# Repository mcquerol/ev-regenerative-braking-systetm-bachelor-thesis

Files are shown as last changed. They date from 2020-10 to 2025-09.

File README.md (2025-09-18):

# ev-regenerative-braking-system-bachelor-thesis

Initial README file.

Report can be found on Researchgate ->

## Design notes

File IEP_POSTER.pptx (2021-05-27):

## A comparison of li-ion cells and supercapacitors in the efficiency of a regenerative braking system for EVs

Introduction
Electric vehicles (EVs) have been around for many years and have since become increasingly popular in society. The rechargeable lithium-ion battery was commercialised in 1985 and since then it has become widespread in many commercial applications such as laptops, cell phones, alarm systems and recently EVs.
A regenerative braking system in an EV consists of taking the car’s kinetic energy and converting it into electrical energy; this energy is stored in Li-ion cells. Recent developments in solid-state storage devices (supercapacitors) could show not only improved performance, but a more environmentally friendly solution.
This project will be a comparison of Li-ion and supercapacitor battery technologies used in the context of a regenerative braking system. The efficiency will be measured by speeding up a DC motor to a set speed for both batteries then measuring the capacities of both batteries after they have been recharged with the back-emf of the DC motor.
Given the financial and time constrains of the project, this will be produced on a small scale, hence why a DC motor is used. The capacities of the Li-ion and supercapacitor battery packs will be limited (but approximately equal to ensure a fair comparison) because of the limited budget of £75.

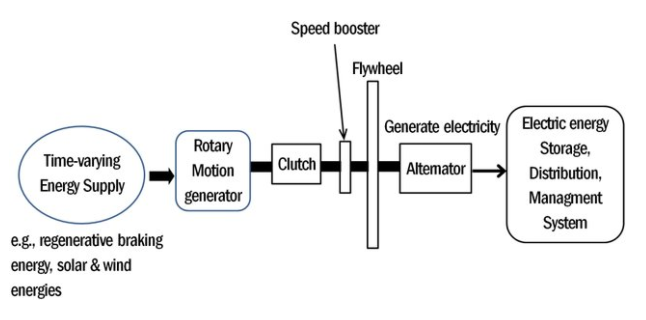
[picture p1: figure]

100448597
Supervisor: David Wilson

Results
For each of the storage devices, the current was motor was sped up to certain (approximate) speeds and the current output of the buck converter was measured. Next, the time the LEDs stayed on was measured using a stopwatch. The % of battery filled was calculated and graphed vs the speed of the motor.
% charged[(Wh)/(Wh)]=((V×I×s)/3600)/(max. capacity)×100%
The supercapacitor proved to have regenerated almost double the amount of the Li-ion cell. This is because the supercapacitor is built to charge and discharge more quickly than the Li-ion cell.
In May 2016, a Tibetan river was contaminated by a nearby mine leak which killed all the fish and destroyed the surrounding ecosystem. The higher the demand for Lithium batteries, the higher the risk of pollution to the environment; cases like these pose the question of needing a more sustainable means of energy storage. Lithium mines around the world are not always in the best working conditions, not supporting the workers with protective equipment can be detrimental to their health and can lead to a disinterest in the future workforce.

Conclusion
Li-ion cells and supercapacitors are both very promising for the future of battery storage technology. In principle, Li-ion batteries are better for long range applications whereas supercapacitors are better for applications that require quick bursts of energy; this was seen through the various measurements taken from the prototype.
EVs are a new, emerging technology that is constantly changing. Now most if not all EV companies (primarily Tesla) are in the Li-ion market. Unfortunately, supercapacitors have not been made widely available yet in the EV market. Supercapacitors have many advantages in terms of the way they store and manage stored power, but the main disadvantage is that there is a very large cost that comes with these devices. With climate change being a concern, this only begs the change to a more sustainable and easy-to-obtain method of energy storage.

PCB and prototype
The brain of this small-scale regenerative braking system is the PIC18F25K22 microcontroller, it controls all the inputs and outputs of the system. The two storage devices: the supercapacitor and Li-ion cell have two different operating voltages (2.5V and 3.7V). The user must have a choice to which one is used at a given time so one of the inputs is selecting the storage device. This tells the PIC how it should step down the back-emf coming from the motor.
A simple button or switch can be used to enable the motor to start moving, once it reaches a certain speed, it is turned off and the back-emf is fed through the buck converter into the storage device. The boost converter then takes said voltage and steps it back up at a level high enough for the PIC to measure current. This is done through a simple voltage divider for the voltage and the current is measured using a transconductance amplifier.
The speed of the wheel attached to the motor and is measured with an optocoupler. The optocoupler is used to measure how many rotations occur in one second and the RPM can be calculated. It is through this measurement that the motor can be stopped after x RPM.

References
Barrera, P. (2020, August 20). Top Lithium Production by Country | Australia is First | INN. Investingnews. https://investingnews.com/daily/resource-investing/battery-metals-investing/lithium-investing/lithium-production-by-country/
Bousbaine, A. (2020). Lecture 5-Boost converters-V1-BB (p. 18).
Cordis. (2018). Clean and green supercapacitors for energy efficiency and transport applications | Results In Brief | CORDIS | European Commission. https://cordis.europa.eu/article/id/148917-clean-and-green-supercapacitors-for-energy-efficiency-and-transport-applications
Emmerich. (2017). 18650 Li ion cell. https://asset.conrad.com/media10/add/160267/c1/-/en/000251007DS01/datasheet-251007-emmerich-icr-18650nh-sp-non-standard-battery-rechargeable-18650-cable-li-ion-37-v-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

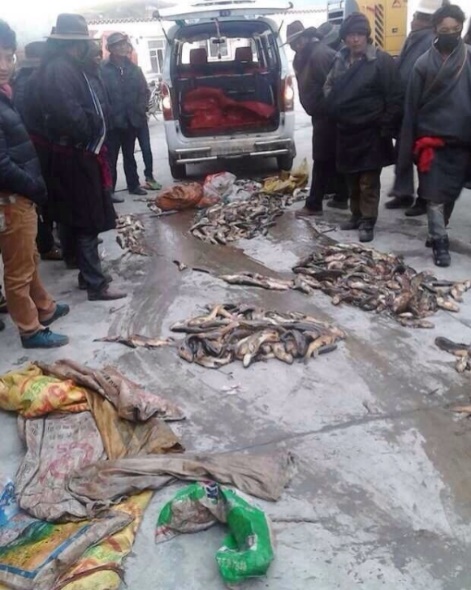
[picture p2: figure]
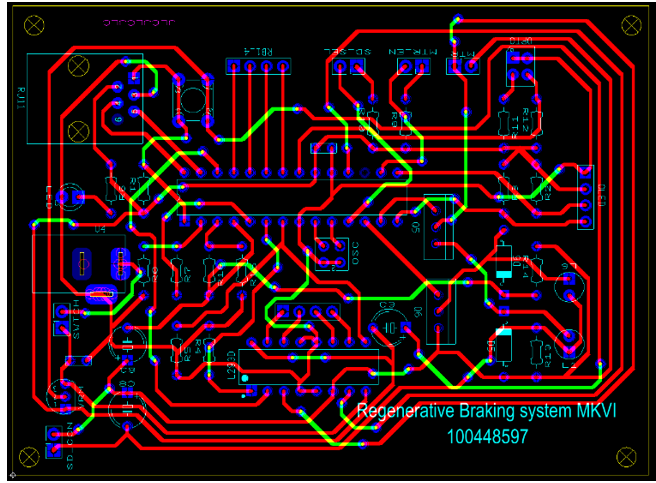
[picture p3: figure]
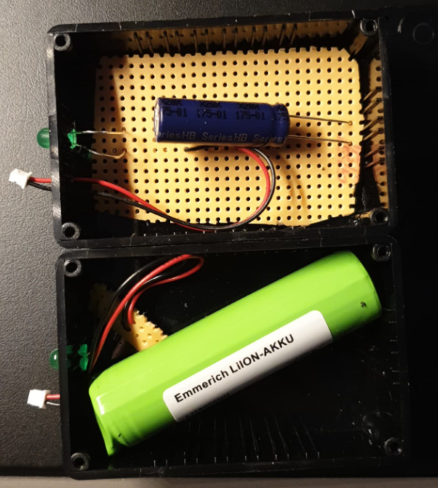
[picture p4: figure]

Li-ion cell & supercapacitor

Storage device

Main system

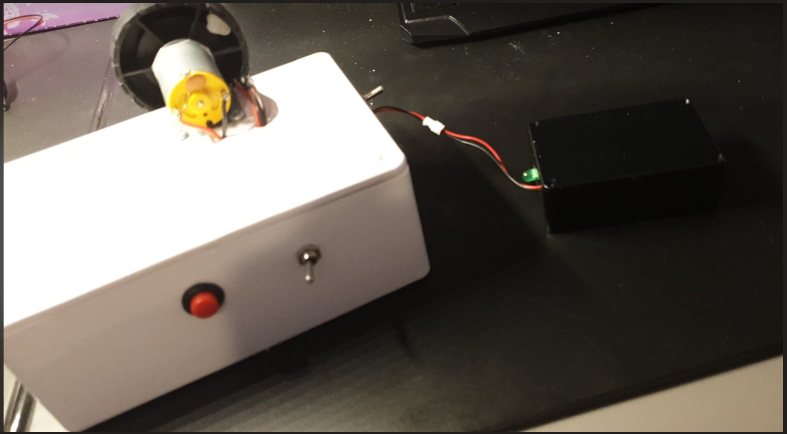
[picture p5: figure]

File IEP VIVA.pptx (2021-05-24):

## A comparison of Li-ion cells and supercapacitors in the efficiency of a regenerative braking system for EVs

By: Mateo Ceballos Querol
100448597
H600 (Hons) BEng Electrical and Electronic Engineering
Supervisor : David Wilson

## Outline

- Introduction
- Aims
- Motivation
- Initial ideas
- Conceptual flowchart
- Design
  - Schematic
  - PCB
  - Prototype
- Coding flowchart
- Results & Analysis
  - Graphs
  - Sustainability & Ethics
- Future recommendations
- Conclusions
- References

## Introduction

- Rise of EVs
- Regenerative braking system
- Concerns of battery technology
- Environmental and ethical issues
- Create prototype

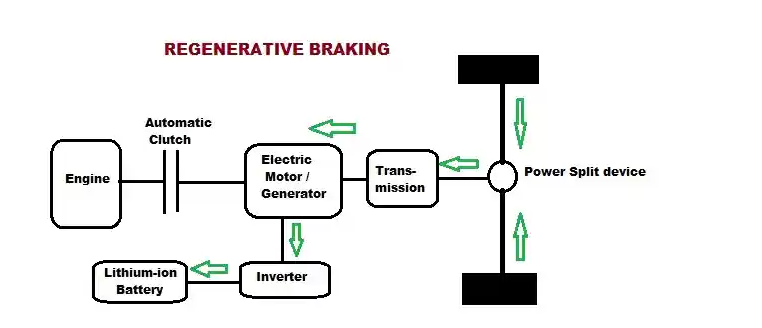
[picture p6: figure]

(Smith, 2014)

## Aims

  - Design and build a regenerative braking system using a DC motor.
  - Measure how much power is regained into each “battery pack” from the DC motor.
  - Provide a more ethically and environmentally sustainable means of manufacturing batteries.
  - Justify the potential change from LI-ion to supercapacitors as the potential power source for EVs.

## Motivation

- Science & Tech
- Electric Vehicles
- Sustainability
- Future interest in embedded systems

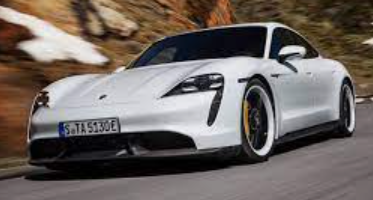
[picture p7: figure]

(Miller, 2019)

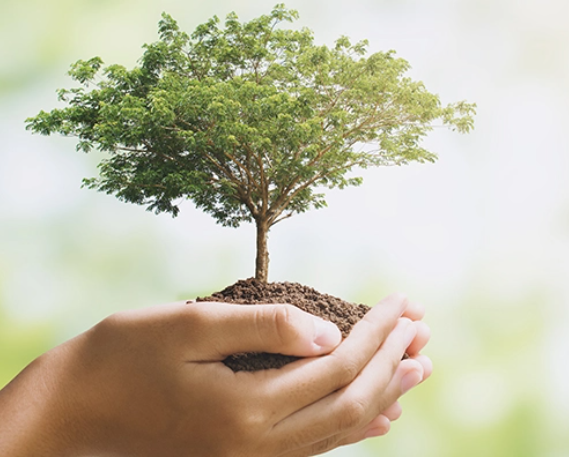
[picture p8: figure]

(Stuart, 2018)

## Initial ideas

- Plan A: Create compact enclosure/PCB
- Develop regenerative braking system as in an EV
- Send data to a PC via USB
- Plan B: Simulink model, more freedom

## Conceptual flowchart

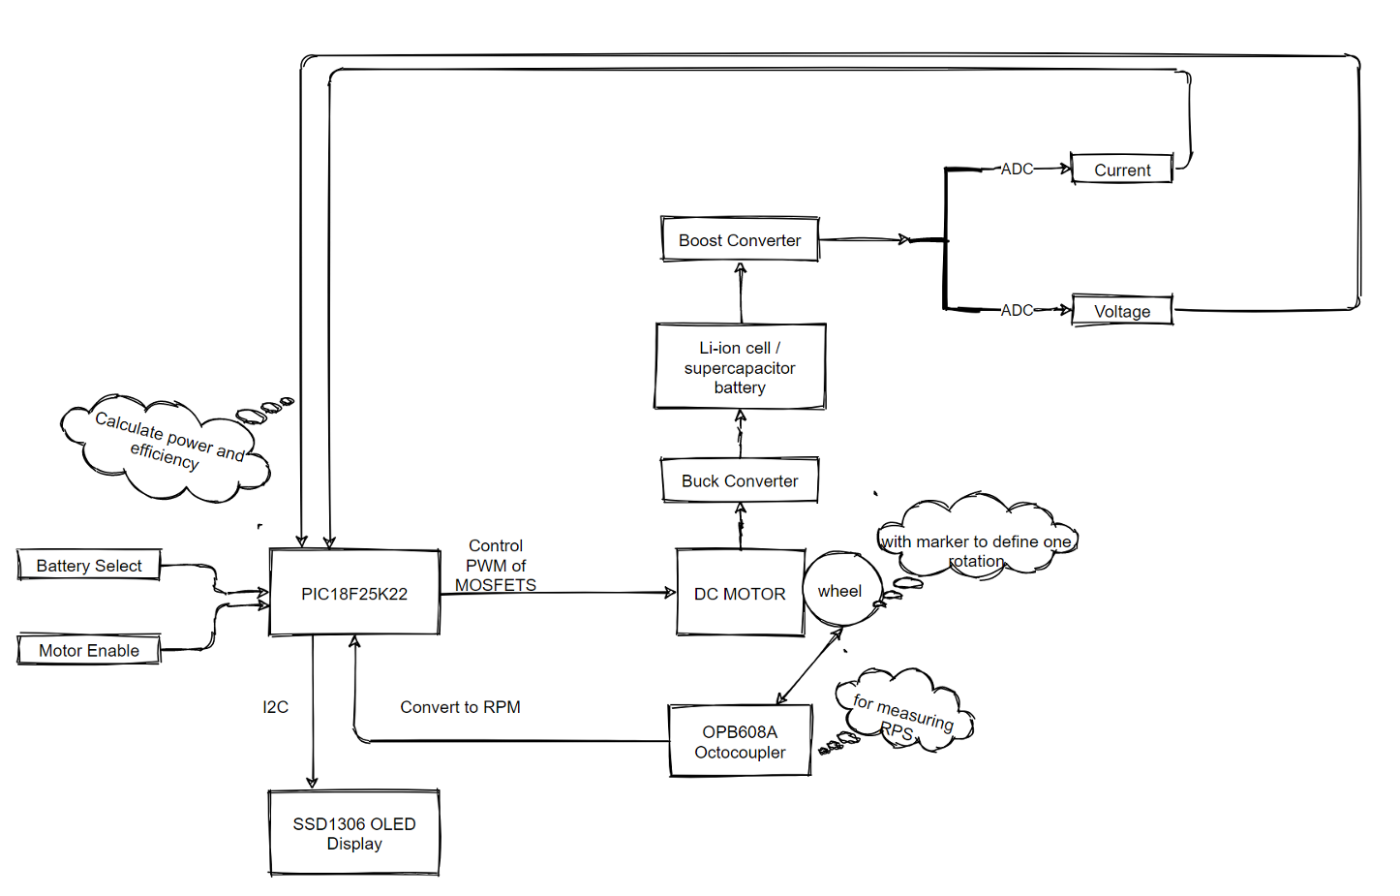
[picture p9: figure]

## Design - Schematic

- PIC18F25K22
- Motor control
- ADC
- I2C
- Optocoupler

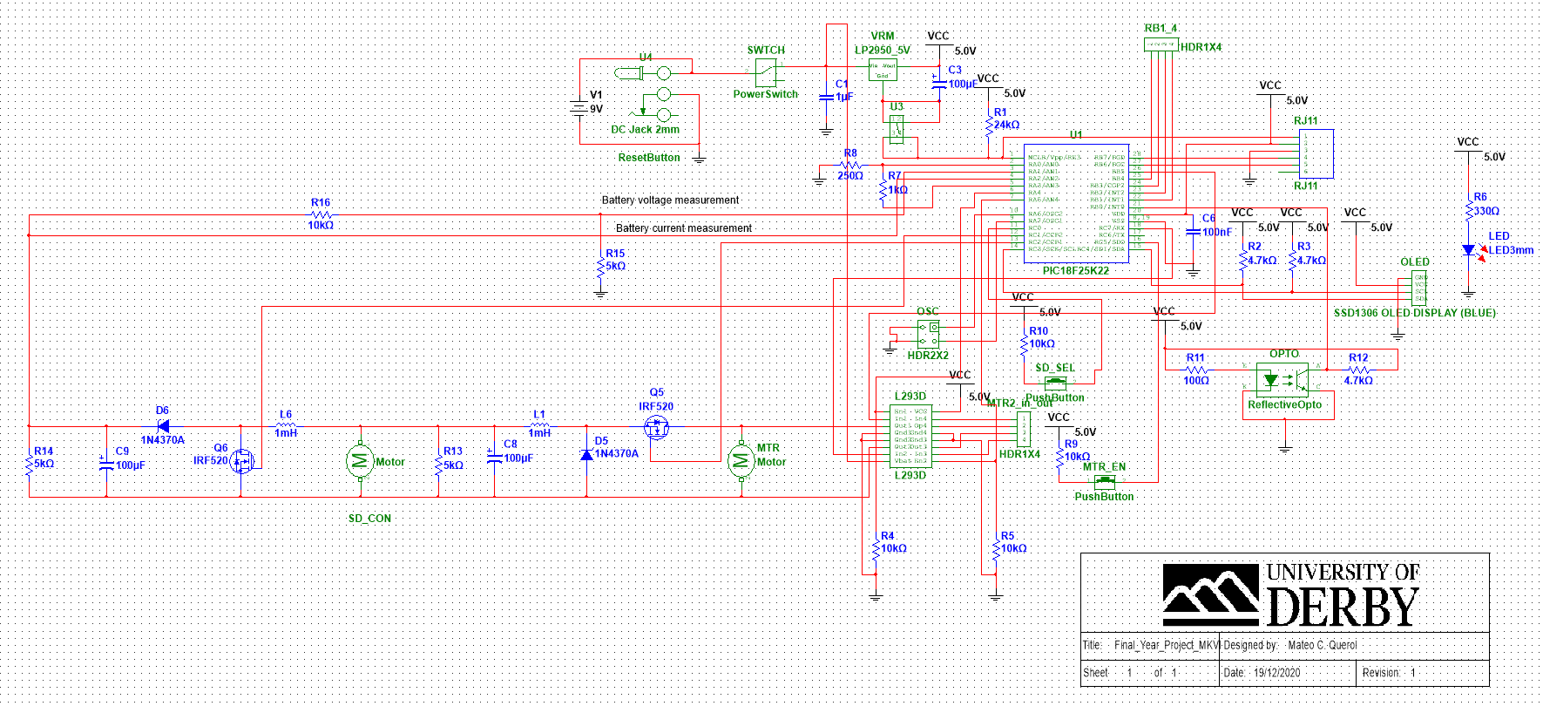
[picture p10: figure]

## Design - PCB

- Arduino-inspired design
- 6 iterations
- JLCPCB

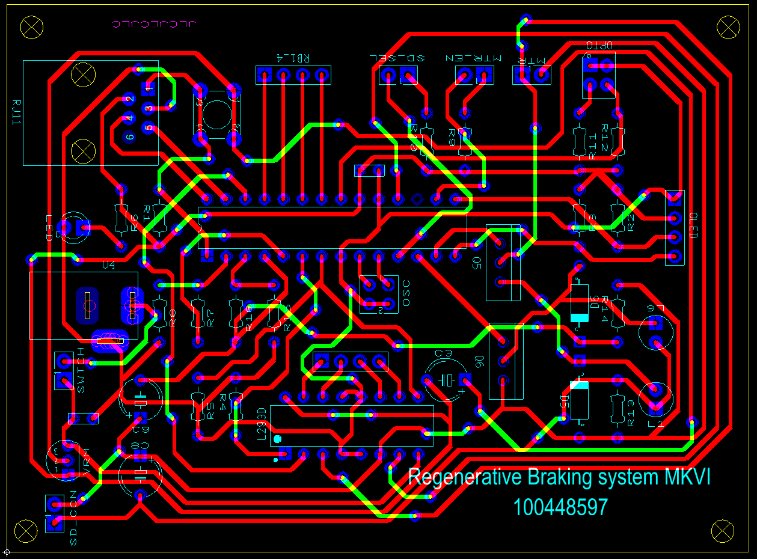
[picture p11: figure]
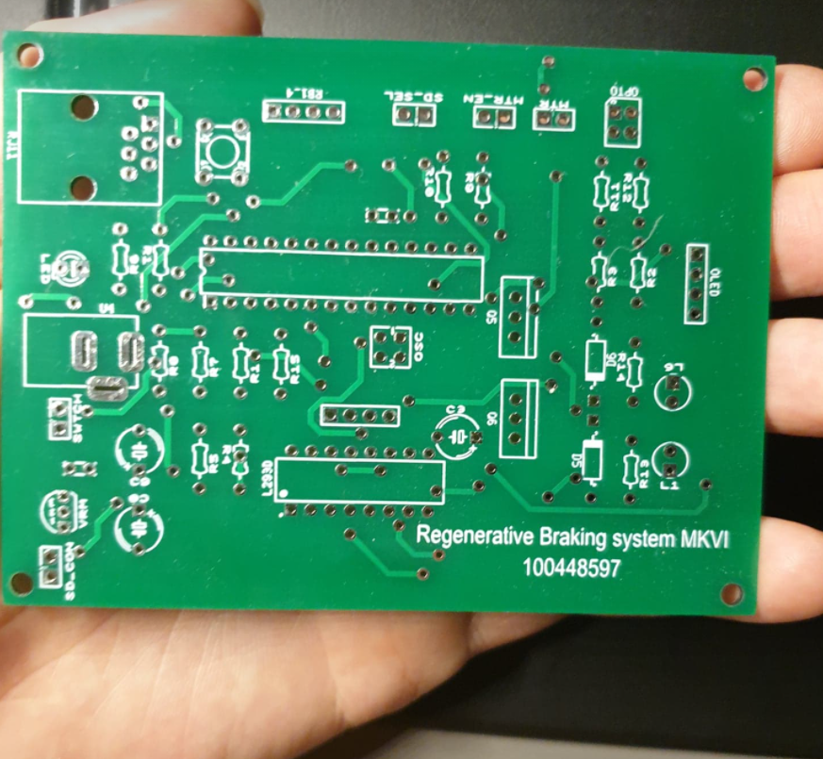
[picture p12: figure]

## Design - Prototype

- Modular design

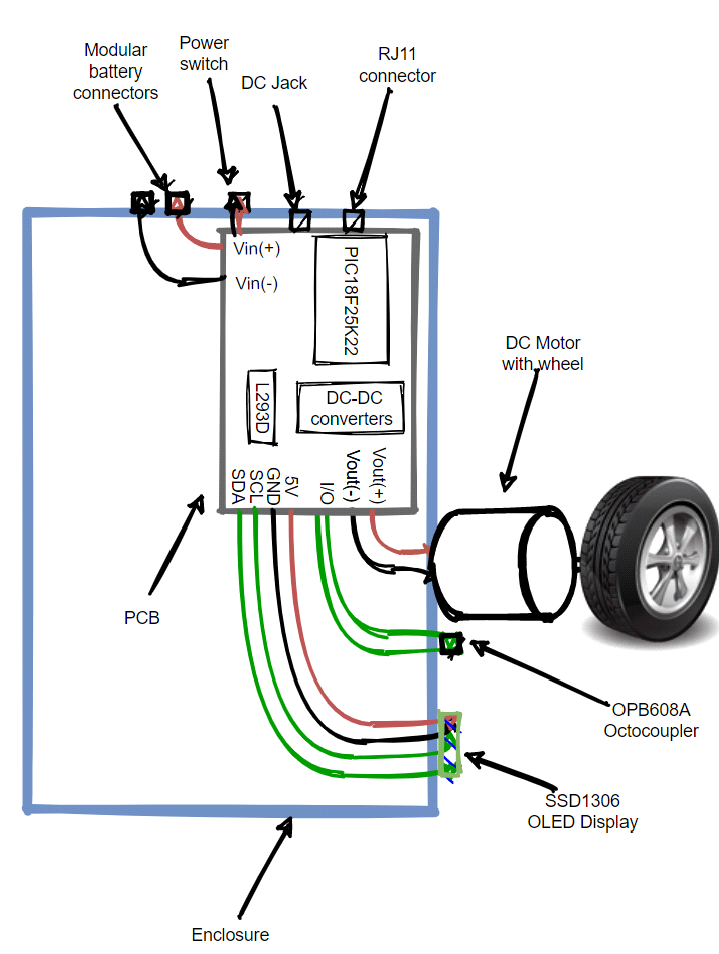
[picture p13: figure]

Storage device


Li-ion and supercapacitor


Main system

## Coding flowchart

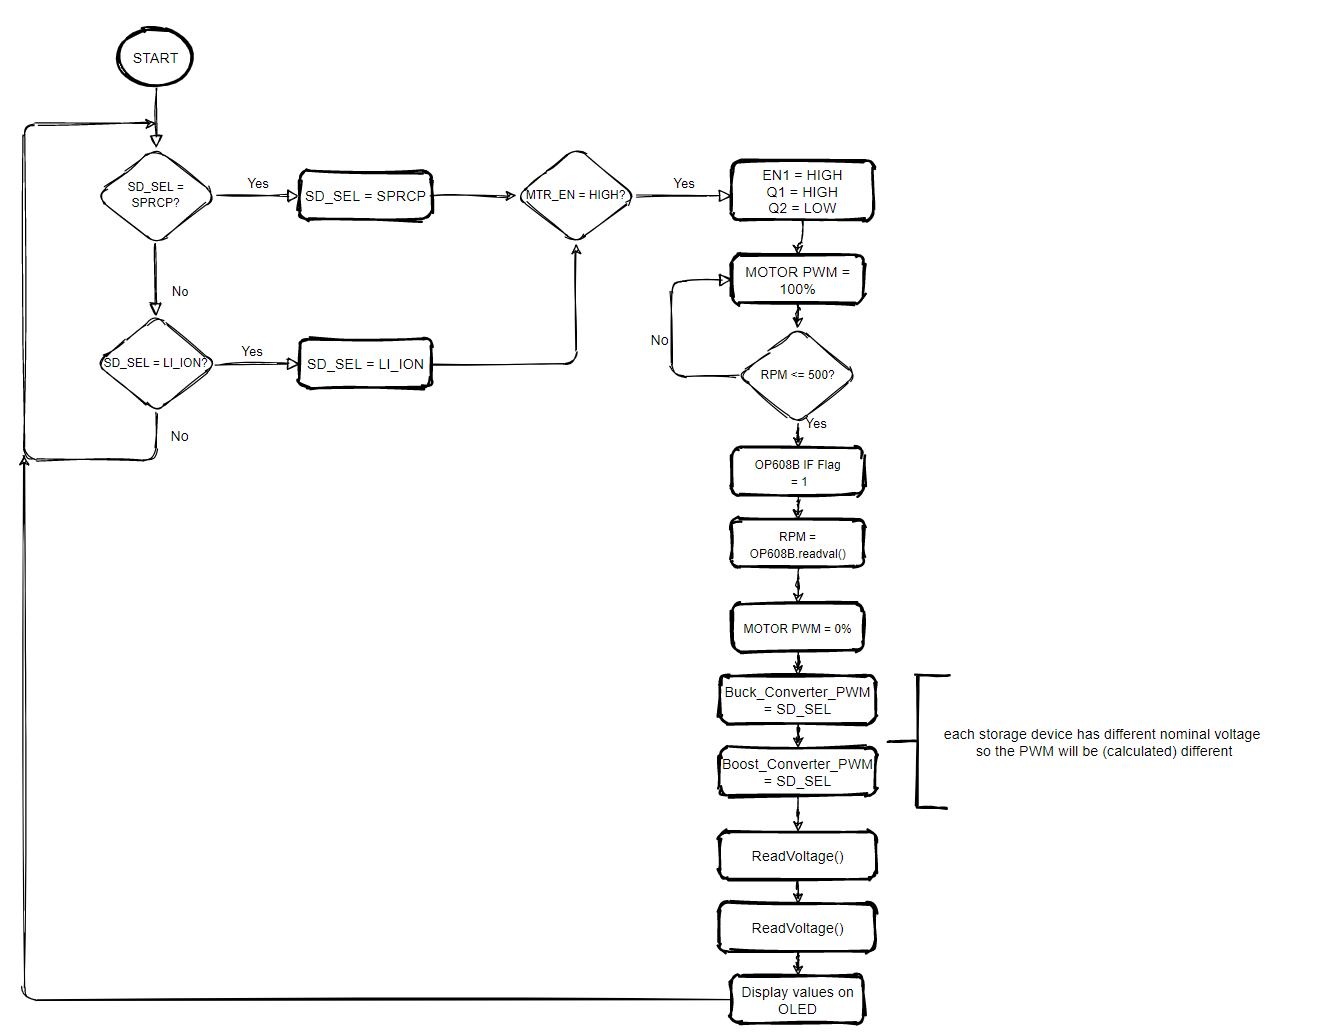
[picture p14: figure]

## Results & Analysis - Graphs

- Li-ion capacity : 8.14Wh
- Supercapacitor capacity : 8.17mWh

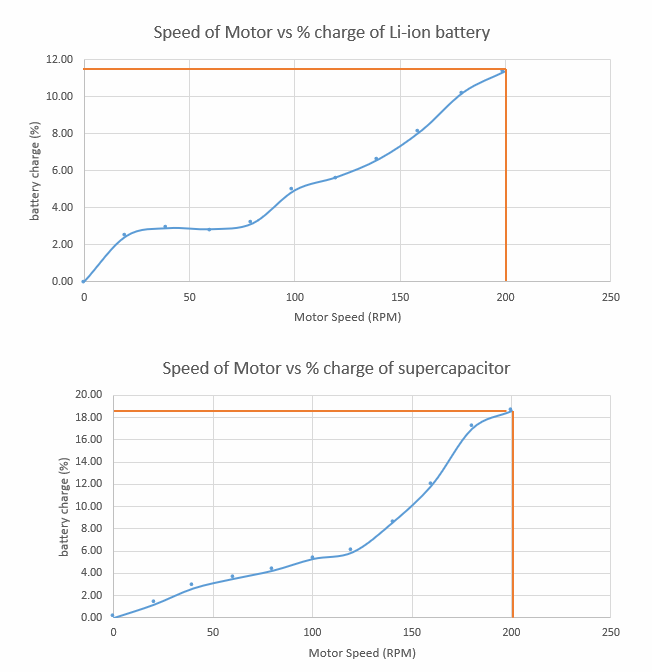
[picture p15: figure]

## Results & Analysis - Graphs

- Max motor speed is 210 RPM
- Max motor power is approx. 1.6W

## Results & Analysis – Sustainability & ethics

- Mine leaks
- Underpaid, non-safe working conditions
- Import/Export
- EU, circular economy

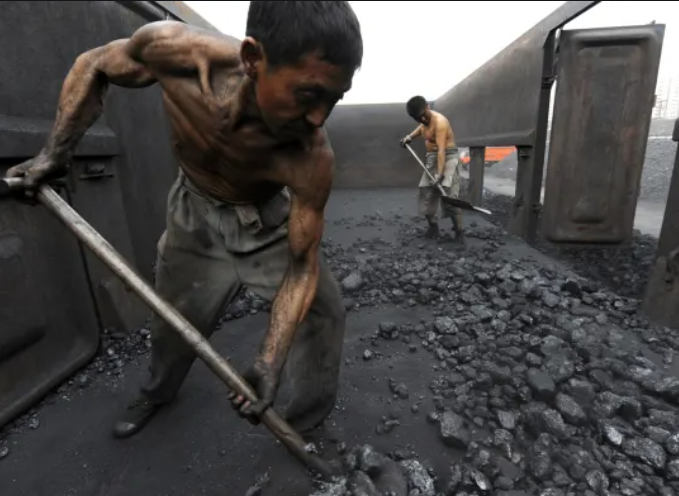
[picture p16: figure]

(Hornby, 2020)

(Song, 2016)

## Future recommendations

- SMD components
- Larger Motor
- Equal storage device capacities
- Possible hybrid Li-ion-supercapacitor battery

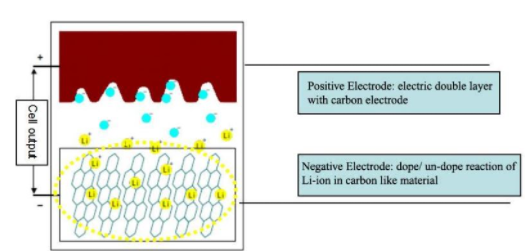
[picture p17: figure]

(Keenan, 2017)

## Conclusion

- Total cost of project = £60.25
- Environmental footprint
- Li-ion batteries are still optimal
- Increase in EV popularity

## References

- Emmerich. (2017). 18650 Li ion cell. https://asset.conrad.com/media10/add/160267/c1/-/en/000251007DS01/datasheet-251007-emmerich-icr-18650nh-sp-non-standard-battery-rechargeable-18650-cable-li-ion-37-v-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
- fleeteurope. (2018). How ethically is lithium sourced by OEMs? | Fleet Europe. https://www.fleeteurope.com/fr/connected-financial-models/global-europe/analysis/how-ethically-lithium-sourced-oems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 ion battery&curl=1
- Garcia, G. (2014). (3) (PDF) Potential environmental impacts of Li-ion batteries and supercapacitors: Toxicity of carbon nanotubes. https://www.researchgate.net/publication/264081052_Potential_environmental_impacts_of_Li-ion_batteries_and_supercapacitors_Toxicity_of_carbon_nanotubes
- HBSupercapacitors. (2018). Supercapacitor. http://www.farnell.com/datasheets/2849566.pdf
- Keenan, M. (2017). Supercapacitor And Li-Ion Technology Combining | Avnet Abacus. https://www.avnet.com/wps/portal/abacus/resources/article/hybrid-capacitors-combine-supercacitor-and-li-on-technology/
- Liu, Z. (2019). Lithium Ion Battery - History - Accelerating Microscopy. Zhao Liu. https://www.thermofisher.com/blog/microscopy/the-history-of-the-lithium-ion-battery/
- Meyer, S. (2019). Child labour, toxic leaks: the price we could pay for a greener future | Green economy | The Guardian. https://www.theguardian.com/environment/2021/jan/03/child-labour-toxic-leaks-the-price-we-could-pay-for-a-greener-future

## Thank you!

Questions?

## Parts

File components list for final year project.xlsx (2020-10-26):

 |  |  |  |  | cabinet | row | drawer
Capacitor | Supercap electrolytic, radial 2.5V (http://uk.farnell.com/bussmann-by-eaton/hb1030-2r5106-r/cap-super-10f-2-5v-rad/dp/2148499?ost=763-7797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) | 0.2"/5.08mm pitch | 10F | £3.78 | 3 | 11 | 3b
IC | PIC18F25K22 (https://onecall.farnell.com/microchip/pic18f25k22-i-sp/mcu-8bit-pic18-64mhz-dip-28/dp/1840992?st=pic18f25k22) | 28Pin DIL (0.3" SPDIP) | - | £2.08 | 11 | 1 | 4b
Crystal | 4MHz Xtal low profile (https://www.rapidonline.com/act-4-0mhz-hc49-s-30-50-4-0-mhz-hc-49-s-l-p-crystal-90-0310) | 0.2" (5.08mm) pitch | - | £0.26 | 11 | 4 | 2
motor | https://www.amazon.co.uk/Motors-Permanent-3500-8000RPM-Generator-8000rpm/dp/B07KPDHSYW |  |  |  |  |  |  |  |  |  |  | 13.49
 |  |  |  |  |  |  |  | item | unit price | quantity | total price
 |  |  |  |  |  |  |  | supercap | 3.78 | 4 | 15.12
 |  |  |  |  |  |  |  | pic | 2.08 | 1 | 2.08
 |  |  |  |  |  |  |  | crystal | 0.26 | 1 | 0.26
 |  |  |  |  |  |  |  | motor | 13.49 | 1 | 13.49
 |  |  |  |  |  |  |  |  |  |  | 30.95

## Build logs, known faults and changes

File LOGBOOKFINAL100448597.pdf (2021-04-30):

30 April 2021 18:53

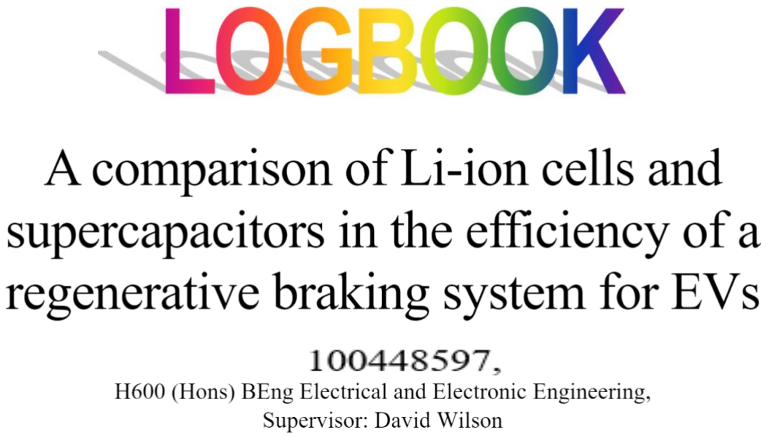
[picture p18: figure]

Initial ideas Page 1

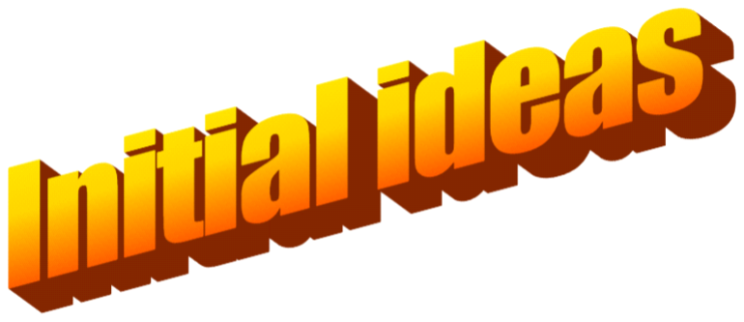
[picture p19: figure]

This section contains:
- Early ideas of what the project would be/look like Alternatives to be taken if it is not possible to design a PCB

•

- Preliminary diagrams

30 April 2021 20:05

Initial ideas Page 2

I want this project to revolve around the topic of electric vehicles as that is one of the many aspects of engineering that led me to study EEE.

I was recently introduced to supercapacitors (about 2 years ago) and I believe they have a great potential in relation with increased efficiency of Evs in the near future. They are more expensive than Li-ion cells (currently used in Evs) but they present great electrical properties.

I think it would be great to do a comparison using both of these battery technologies and see which one is more efficient. Something I wanted to do since foundation year (2017) when I first started gathering ideas for this final year project was to build a regenerative braking system.

Ideally I would want to use a 3-phase AC induction motor as that is what is used in Evs such as Teslas but due to the nature of the project: the fact that it's just me working on it and I have limited time and am on a budget, it is best to use DC motor. An AC motor would cost much more and functions with very high (mains) voltages and requires an inverter; dealing with AC if I don't know what I'm doing is not the safest thing in the world

Something else that really interests me is sustainability and helping save the planet. I want to not just investigate which battery would be a more viable solution for a more efficient EV but also I want to have a look at the environmental and ethical issues regarding the manufacturing and transport processes of these technologies.

For example, Lithium needs to be extracted from mines and miners doesn't always have the best working conditions and are underpaid etc.

Lithium batteries are used for many industrial and commercial applications so it means that there will always be a high demand for LI-ion batteries; at least until a new battery technology is introduced into the market and is deemed more viable (could it be supercapacitors?)

Only a small few countries around the world are large extractors of Lithium for Li-ion battery production and it means there will always be a demand for the mineral which will result in a huge production of batteries. The extraction, production and exportation of these all contribute to a carbon footprint.

I am currently not sure about the manufacturing process that is involved in the production of supercapacitors but I believe it does not have such a large carbon footprint as Li-ion batteries because it requires more locally available resources (including copper for the plates). However there is a difference between supercapacitors and regular electrolytic capacitors that are used in small RC circuits

I want the theme of efficiency to be a recurring idea in my final report, not just in terms of the back-emf generated by the motor but also the manufacturing process of each of the batteries.

I'm thinking that the result of this will be that the supercapacitor is the ideal of the two because of how easy it would charge and discharge but maybe it will not be viable due to other factors

The hardware will be something like what I did in engineering workshop in year 1. A small enclosure containing all the components (µC, DC motor and bidirectional DC-DC converter) the PIC18F25K22 will be used as the brain of the entire operation. The DC-DC converter uses mosfets to determine the flow of current, they can be controlled by the PWM generated by the PIC. Their duty cycle determines the input and output voltages which will be important when switching between the Li-ion and supercapacitor batteries and their nominal voltages are slightly different.

I like the way the Arduino UNO devboard PCB is laid out and I plan to have a very similar layout when it comes to placing the components on ultiboard.

First ideas

07 October 2020 20:38

Initial ideas Page 3

# If the main idea does not occur due to COVID pandemic, the entire project can be built using the Simscape and Simscape electrical and specialized power system libraries included in Simulink. This would be easier to build and data acquisition

would be much easier than the hardware.

# If I need to resort to plan B then I would still like to make a schematic, PCB showing what the finished product would've looked like as well as a list of components to ensure that the total cost of the project would've been less than 75 pounds

# Plan B

31 October 2020 17:55

Initial ideas Page 4

This project will require some measurements. The idea for the regenerative braking system is that the motor is sped up to x speed and then the back-emf as well as the temperature of each of the batteries will be measured. Once the data can be recorded, it can be graphically represented on excel or MATLAB and then that can be used for analysis within the report.

These are the necessary measurements
- Back-emf for each battery (using ADC from PIC)
Temperature, possibly with an NTC thermistor (might require INA) (also using ADC from PIC)

•

RPM speed - to speed up the motor to x speed before back-emf is generated (an octocoupler can be used, if this is the case then a marker of some kind will be needed to indicate 1 revolution, from this the speed in km/h or mph can be calculated.

•

I would like to display the information on a blue OLED screen because Dave likes blue LEDs and it will look cool. The problem is this uses I2C which may pose some difficulties when programming the displaying of data and also I would need to find a way to make it visible when it is a finished product so I would need to cut a hole in the enclosure somehow. Fortunately for me, money is not much of a problem because I've seen blue text OLED screens for as low as 3 or 4 pounds on amazon.co.uk

Required Measurements

30 October 2020 20:16

Initial ideas Page 5

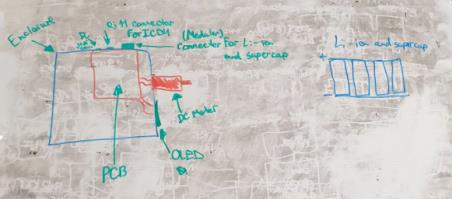
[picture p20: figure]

Here is a rough design of the hardware design. It shows the PCB inside the enclosure with all the peripherals
To reduce the costs, I plan to have a modular design where the Li-ion cell(s) and supercapacitor is attached to the input of the buck-boost converter though I am yet unsure as to how exactly I will make the connection. I don't want to make 3 PCBs as it will be time consuming and would cost more resources to make but I think the idea of having a modular (plug and play) design could work.
I am also unsure of how many Li-ion cells and supercapacitors I will use, I will need to take into account the price when it comes to the shopping list. Li-ion cells have far greater capacity (mAh) per cell than supercapacitors so I'm not sure if it's best to have similar capacities or if I should just get one of each to reduce costs; I think I will go for the latter option.

The design also includes the OLED to display the measured data and the RJ11 connector to connect with the ICD4 to program the PIC

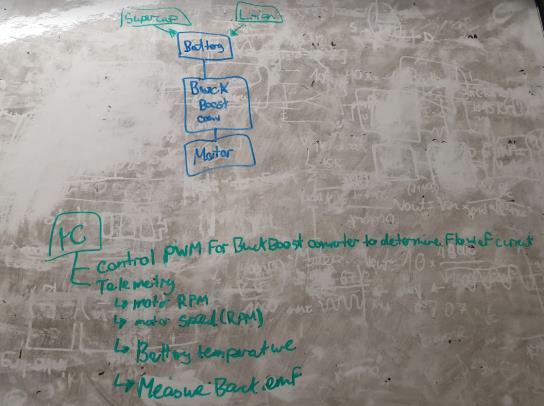
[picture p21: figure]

This was an attempt at drawing a block diagram aka the conceptual design. This was the very first thing drawn for the final year project and does not have a lot of the details but it is a start

Check DESIGNS tab for the final conceptual, hardware and software designs

First sketches

31 October 2020 19:49

Initial ideas Page 6

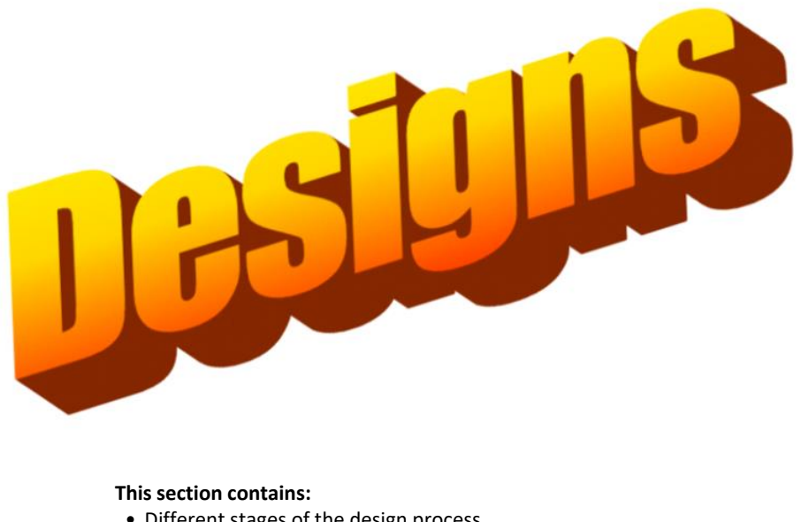
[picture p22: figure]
This section contains:

- Different stages of the design process
- Schematic design
- PCB design

30 April 2021 19:41

Designs Page 7

This is the conceptual diagram of the project, I first made this as soon as the project supervisors were assigned. It shows all aspects of what the project needs to do and how. I believe this is self-explanatory and I can always look back to this if I am lost

Conceptual design

29 October 2020 20:41

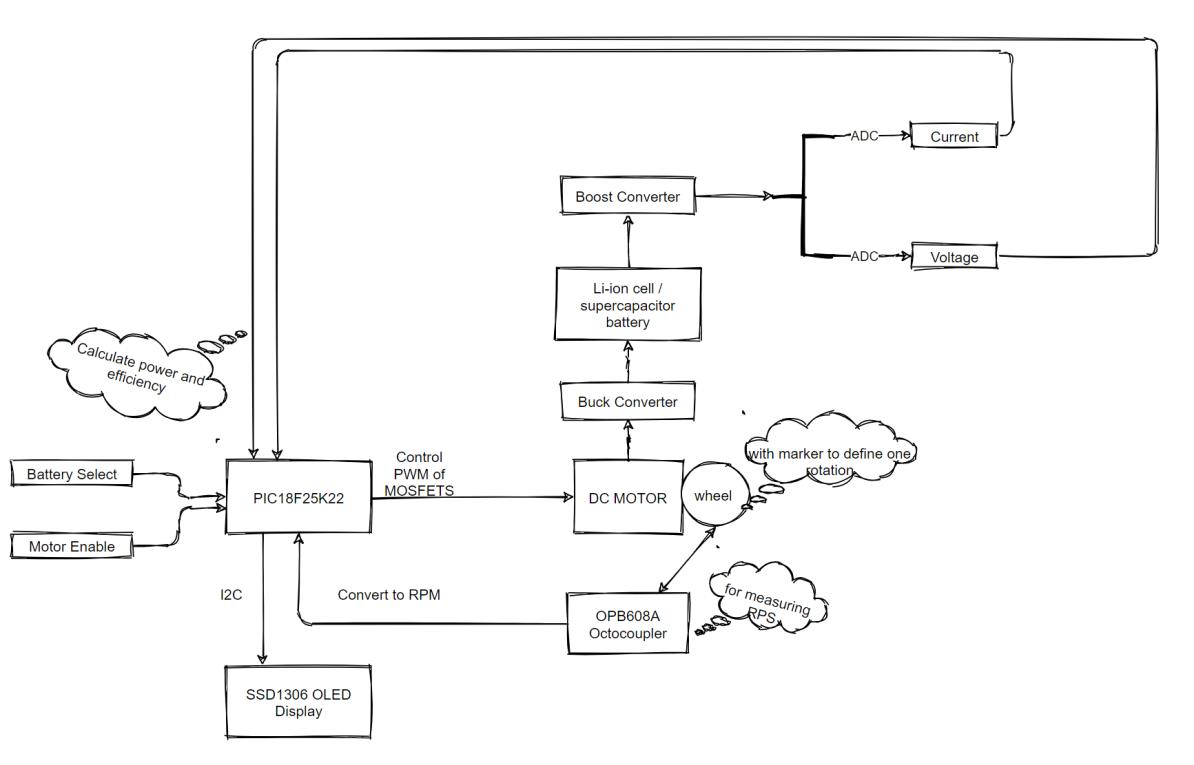
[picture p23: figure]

Designs Page 8

# This diagram is the hardware schematic. This was the first diagram that was made after the initial idea for the IEP. I added

as much structure and order to the hardware as possible,

# meaning that nothing will be out of place and i/o is placed

accordingly.

# The PCB was designed as close as possible to this (CHECK PCB TAB FOR DESIGNS). Headers were placed on the edge of the PCB as to make it easy to solder wires leaving the board

# Hardware Design

30 October 2020 01:10

Designs Page 9

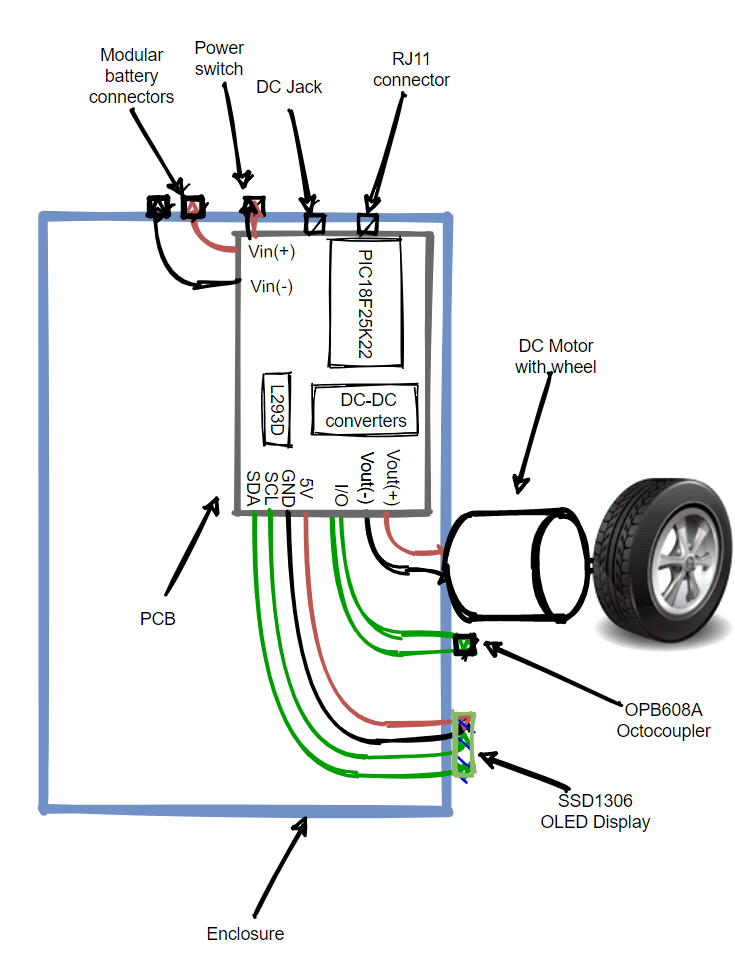
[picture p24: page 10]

Designs Page 10

This shows the flowchart for the software side of the project. This is a very simple descprition of the process start to finish. The storage device is selected, the motor is turned then the back-emf goes through the buck converter, into the battery itself then finally into the boost converter where the voltage and current measurements are taken. Finally, the data is displayed in an OLED display

To make this fair, the same experiment will be carried out for both the Li-ion cell as well as the supercapacitor. The duty cycle of the PWM signals to the buck and boost converters determine the output voltage of each. This will be calculated for each of the storage devices, taking into account that the nominal voltage of the Li-ion cell is 3.7V and for the supercapacitor it is 2.5V

Software design

30 October 2020 01:11

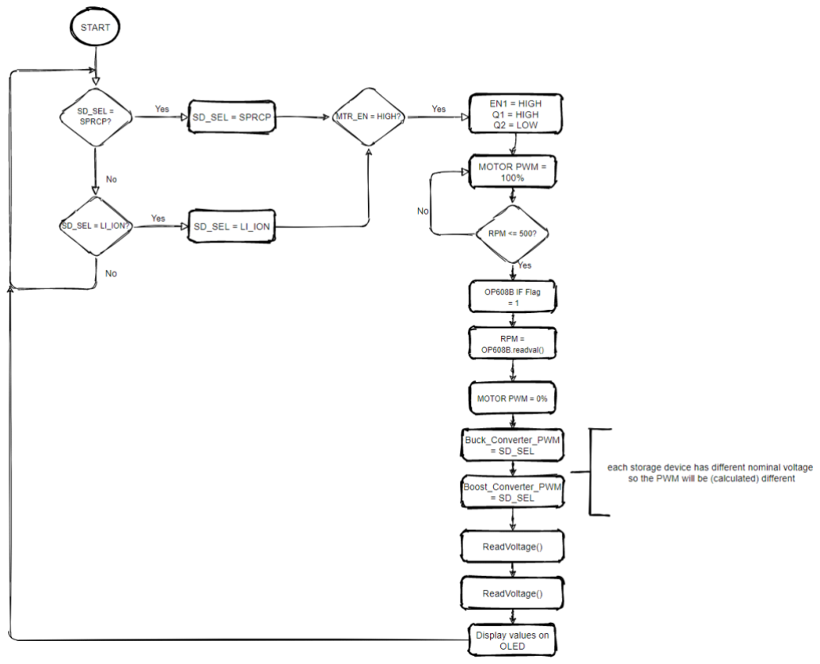
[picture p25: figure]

Designs Page 11

This is the 6th and final iteration for this project's schematic. Each iteration added a bit more than the next or changed it slightly.

The buck and boost converters were tested on a separate multisim schematic to ensure that they accommodated the nominal voltages for both a Li-ion cell and supercapacitors used (3.7 and 2.5V respectively)

Not all pins were used, because of this, headers were connected to ports such as OSC1 and OSC2 (4MHz crystal oscillator was not available so internal oscillator of
PIC18F25K22 will be used as clock) and B ports 1 through 4 as well as a second motor inputs and outputs on the L293D. These are clearly labeled in the refdes which make it easier to identify certain pins when the pcb is printed

Schematic

30 October 2020 01:13

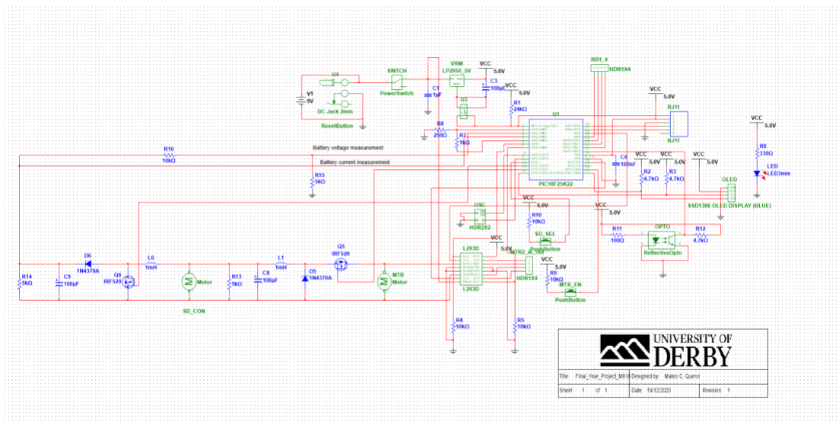
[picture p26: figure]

Designs Page 12

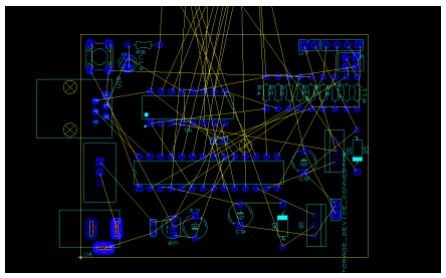
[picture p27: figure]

This is the final PCB, the 6th iteration. It was initially going to be the size of an arduino (63x58mm) as that is very small and compact. However, after a few tries it was deemed very difficult due to having 2 ic's (PIC+L293D) as well as the many resistors going all over the place.

As in the schematic, unused pins were assigned to headers and will be there for future use, the refdes helps identify those pins; such as RB1_ 4 or the input and output pins on the L293D for the use of a second motor

The final dimensions of the PCB is 99x73mm, an enclosure was bought initially to house the first pcb design's dimensions but after the final PCB was made, a new box had to be bought which could fit the new dimensions. Thankfully, this new box was not very expensive and there was still room in the budget to spend on components

PCB

19 December 2020 01:07

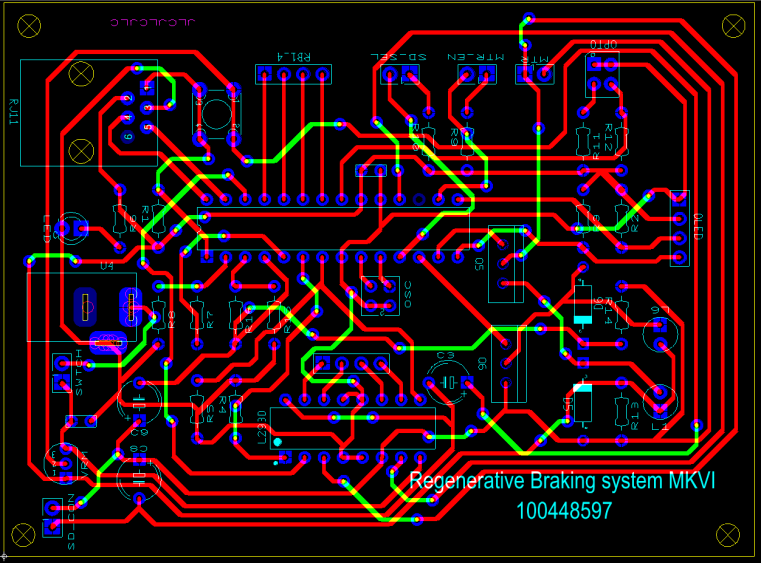
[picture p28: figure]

Designs Page 13

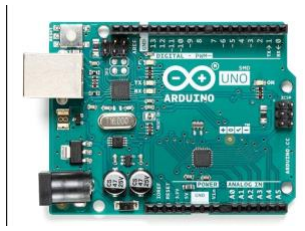
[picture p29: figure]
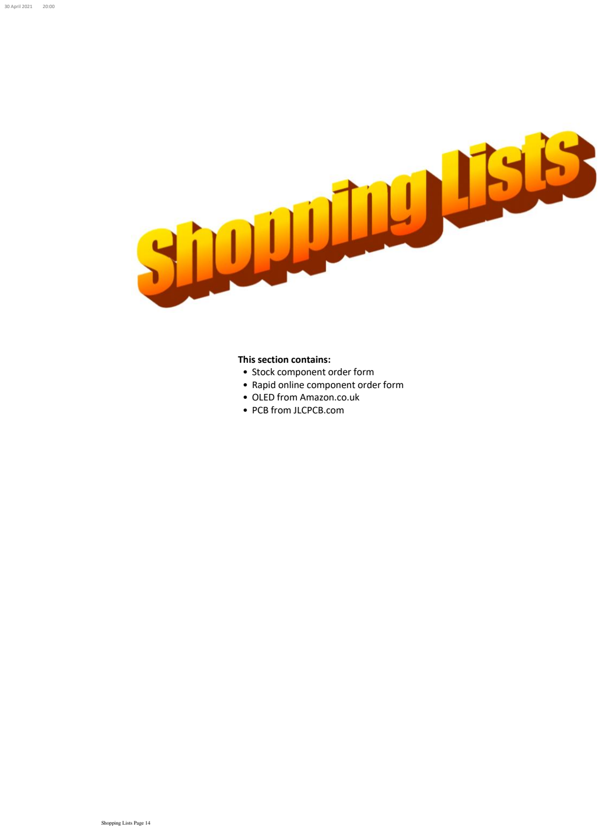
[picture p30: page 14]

This section contains:
- Stock component order form
- Rapid online component order form
- OLED from Amazon.co.uk
- PCB from JLCPCB.com

30 April 2021 20:00

Shopping Lists Page 14

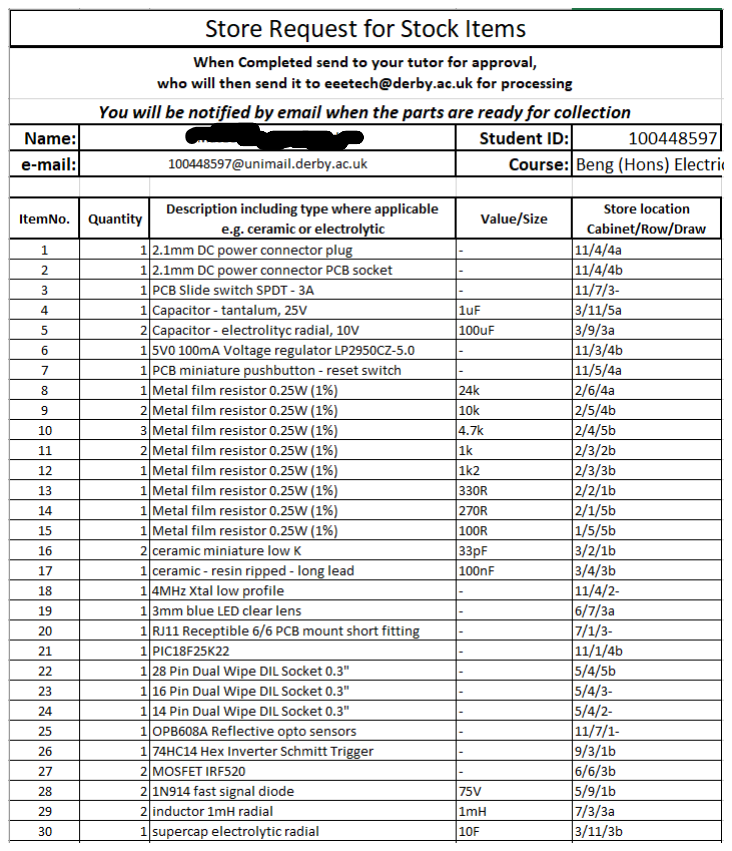
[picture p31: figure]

This is the stock component ordering from the university of derby. The quantity, description, value (if any) and the location in storage.

Total cost of everything including the non-stock components/items came to £60.25

Stock components

29 October 2020 21:29

Shopping Lists Page 15

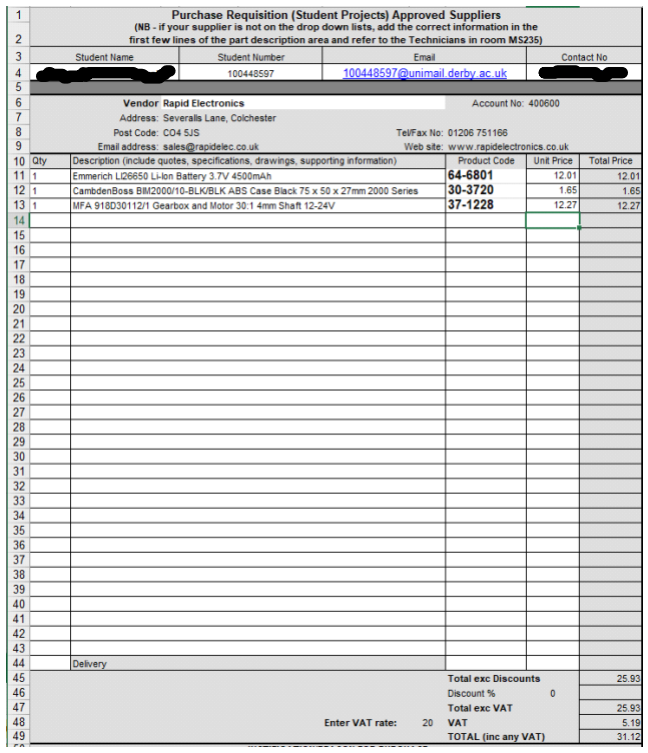
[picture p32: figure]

### Only 4 items were not bought from the stock component's list. These three from rapid online: the Li-

ion battery, the enclosure and the motor.

### Rapid-online

01 November 2020 12:15

Shopping Lists Page 16

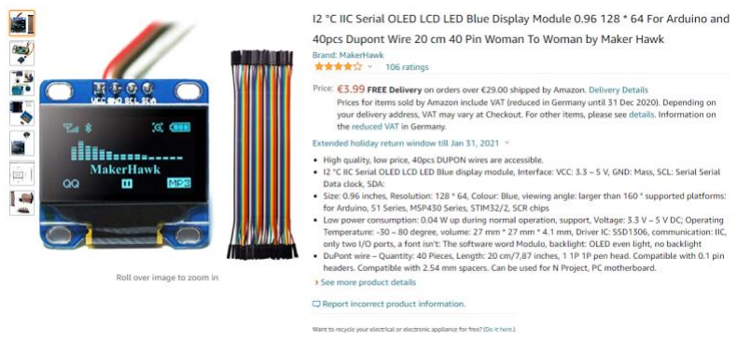
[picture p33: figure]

This 4th item is the oled display and will be used to display the data such as rpm, voltage, current and efficiency

Amazon.co.uk

01 November 2020 15:58

Shopping Lists Page 17

The PCB for this project was not obtained from the university of derby but from an external company, JLCPCB. This adds to the overall cost of the project but there is still room left within the budget of 75 pounds if necessary

This is a top view of the PCB

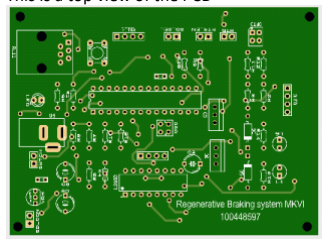
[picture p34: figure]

This is a bottom view of the PCB

PCB

19 December 2020 18:44

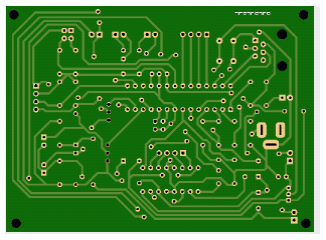
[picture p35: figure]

Shopping Lists Page 18

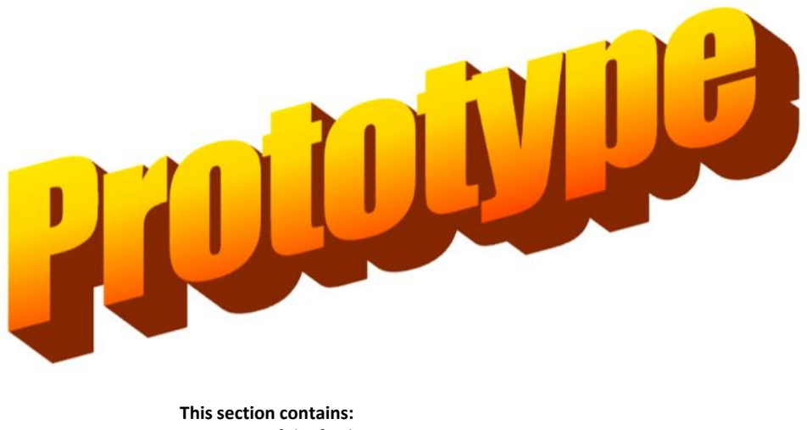
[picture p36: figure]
This section contains:

- Images of the final prototype
- PIC peripherals used/ mcc

30 April 2021 18:59

Prototype Page 19

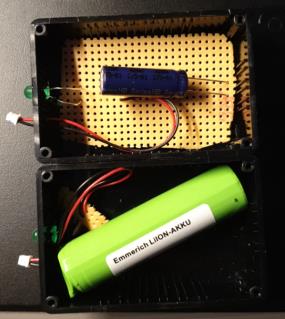
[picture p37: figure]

This image shows the two storage devices placed in their own little boxes. They connect to the main board through that micro connector

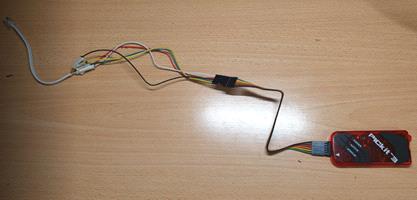
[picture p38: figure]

Unfortunately I was not able to use an ICD4 so instead I used an RJ11 cable and cut it in half and soldered each of the cables to its respective cable on the PCKit3. While this did not allow for debug mode, it allowed for me to program the PIC

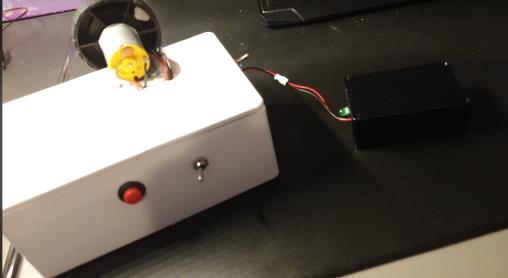
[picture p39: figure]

This is a final image of the prototype with one of the batteries attached. If it was not for the hardware design, this would not have been possible and it probably would not work

Prototype photos

07 April 2021 20:22

Prototype Page 20

Periphe ral | Function | Use in the prototype
ADC | Convert analogue signals into digital values | The ADC was used to measure the voltage across and the current through the boost converter
CPM2 | Selects the signal to be connected to the positive terminal of the Comparator module. | Used as a replacement for an op-amp, external resistors are connected to form a transimpedance amplifier.
ECCP1 | Enhanced PWM mode 1 | This PWM signal is what will control the MOSFET of the buck converter
ECCP2 | Enhanced PWM mode 2 | This PWM signal is what will control the MOSFET of the boost converter
ECCP3 | Enhanced PWM mode 3 | This PWM signal is what will control the motor.
TMR0 | Internal timer 0 | This is the internal timer used for counting the number of turns the wheel makes in 1 second
TMR2 | Internal timer 2 | This timer is used by the 3 ECCP
GPIO | General Purpose Input Output pins | These are other I/O that was used in the project such as: storage device select switch, motor start button and RCL&SDA

This is a summary of the peripherals used in the PIC with their functions and uses

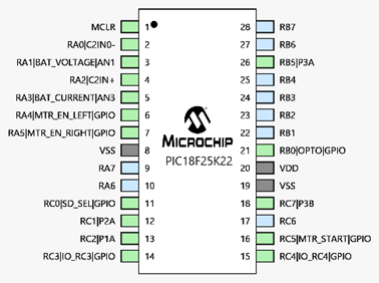
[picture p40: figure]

This diagram is a visual representation of the PIN layout of the PIC. The blue pins are either unused (RA6&7, RC6, RB1-RB4) or reserved (RB6&7)

I did this as soon as the proposal was approved, that way, for the next time I opened MPLAB X I would know what I'm doing.

My idea with the PIC is to measure the current and then for each of the storage devices plot how much % of the max capacity has been regenerated vs the speed of the motor. I expect it to be proportional and I hope to get large regeneration values

MCC resources

10 March 2021 20:22

Prototype Page 21

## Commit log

2020-10-26 added components list for final year project.xlsx
    [components list for final year project.xlsx]
2020-11-15 added flowchart_diagram.drawio
2020-11-15 added flowchart_diagram (2).drawio
2020-11-15 added flowchart_diagram (3).drawio
2020-12-11 added IEP_PCB\Final_Year_Project_MK4 - Board Outline.gbr
    [Final_Year_Project_MK4 - Board Outline.gbr]
2020-12-11 added IEP_PCB\Final_Year_Project_MK4 - Copper Bottom.gbr
    [Final_Year_Project_MK4 - Copper Bottom.gbr]
2020-12-11 added IEP_PCB\Final_Year_Project_MK4 - Copper Top-Copper Bottom.drl
    [Final_Year_Project_MK4 - Copper Top-Copper Bottom.drl]
2020-12-11 added IEP_PCB\Final_Year_Project_MK4 - Copper Top.gbr
    [Final_Year_Project_MK4 - Copper Top.gbr]
2020-12-11 added IEP_PCB\Final_Year_Project_MK4 - Drill Info.rep
2020-12-11 added IEP_PCB\Final_Year_Project_MK4 - Drill Symbols-Copper Top-Copper Bottom.gbr
    [Final_Year_Project_MK4 - Drill Symbols-Copper Top-Copper Bottom.gbr]
2020-12-11 added IEP_PCB\Final_Year_Project_MK4 - Drill-Copper Top-Copper Bottom.gbr
    [Final_Year_Project_MK4 - Drill-Copper Top-Copper Bottom.gbr]
2020-12-11 added IEP_PCB\Final_Year_Project_MK4 - Silkscreen Bottom.gbr
    [Final_Year_Project_MK4 - Silkscreen Bottom.gbr]
2020-12-11 added IEP_PCB\Final_Year_Project_MK4 - Silkscreen Top.gbr
    [Final_Year_Project_MK4 - Silkscreen Top.gbr]
2020-12-11 added IEP_PCB\Final_Year_Project_MK4 - Solder Mask Bottom.gbr
    [Final_Year_Project_MK4 - Solder Mask Bottom.gbr]
2020-12-11 added IEP_PCB\Final_Year_Project_MK4 - Solder Mask Top.gbr
    [Final_Year_Project_MK4 - Solder Mask Top.gbr]
